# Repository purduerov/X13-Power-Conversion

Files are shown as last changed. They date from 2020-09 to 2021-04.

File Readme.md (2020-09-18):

# Readme for X13-Power-Conversion

Whenever you make a new part, download the datasheet and save it here _**and**_ with the part in the parts library

Always pull other people's changes before beginning to work
`git pull`

Be sure to push your changes after  working on them. Run:
1. `git add .` to add any files in this directory or a subdirectory
or `git add -u` to add any modified files
2. (Optional) `git clean -nX` to see what ignored files can be removed
	`git clean -fX` removes ignored files (Eagle backups)
3. `git commit -m "helpful commit message"` with a description of the work that you did
4. `git push` to push your work to github

Other helpful commands
* `git status` says information about modified and staged files
* `git log` shows the recent commits of the repository
* `git log filename.extension` show the recent commits for just that file
* `git checkout first-couple-letter-of-commit-id` lets you go back to a previous version
* `git checkout master` brings you back to the latest commit
* `git tag` lists the tags
* `git tag -a orderX -m "the version of the board placed for the X'th order"` tag a specific commit
* `git push --tags` needed to push tags to remote
* `git show orderX` show the commit log for the given tag
* `git checkout orderX` go back and interact with the files at the tagged commit

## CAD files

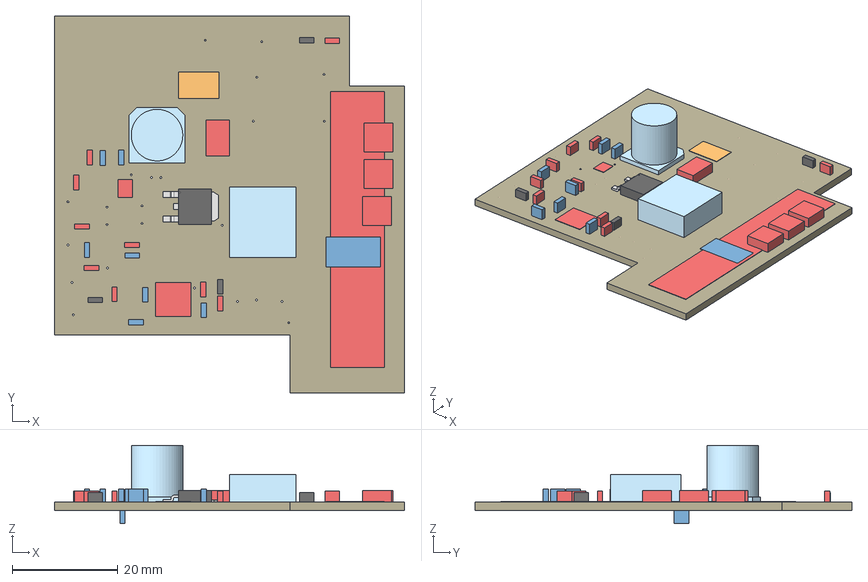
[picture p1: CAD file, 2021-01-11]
PowerConversionBoard.step
66.0 x 71.1 x 14.7 mm
Board
BANANA_CONN x 3
LED-0603 x 3
1.2 Ohms x 9
AZ1117EH-3.3TRG1
LM5085
SO08
4.7uF x 8
47uF
100uF
SWITCHMODE_SCHOTTKY
CON2DIST
15uH

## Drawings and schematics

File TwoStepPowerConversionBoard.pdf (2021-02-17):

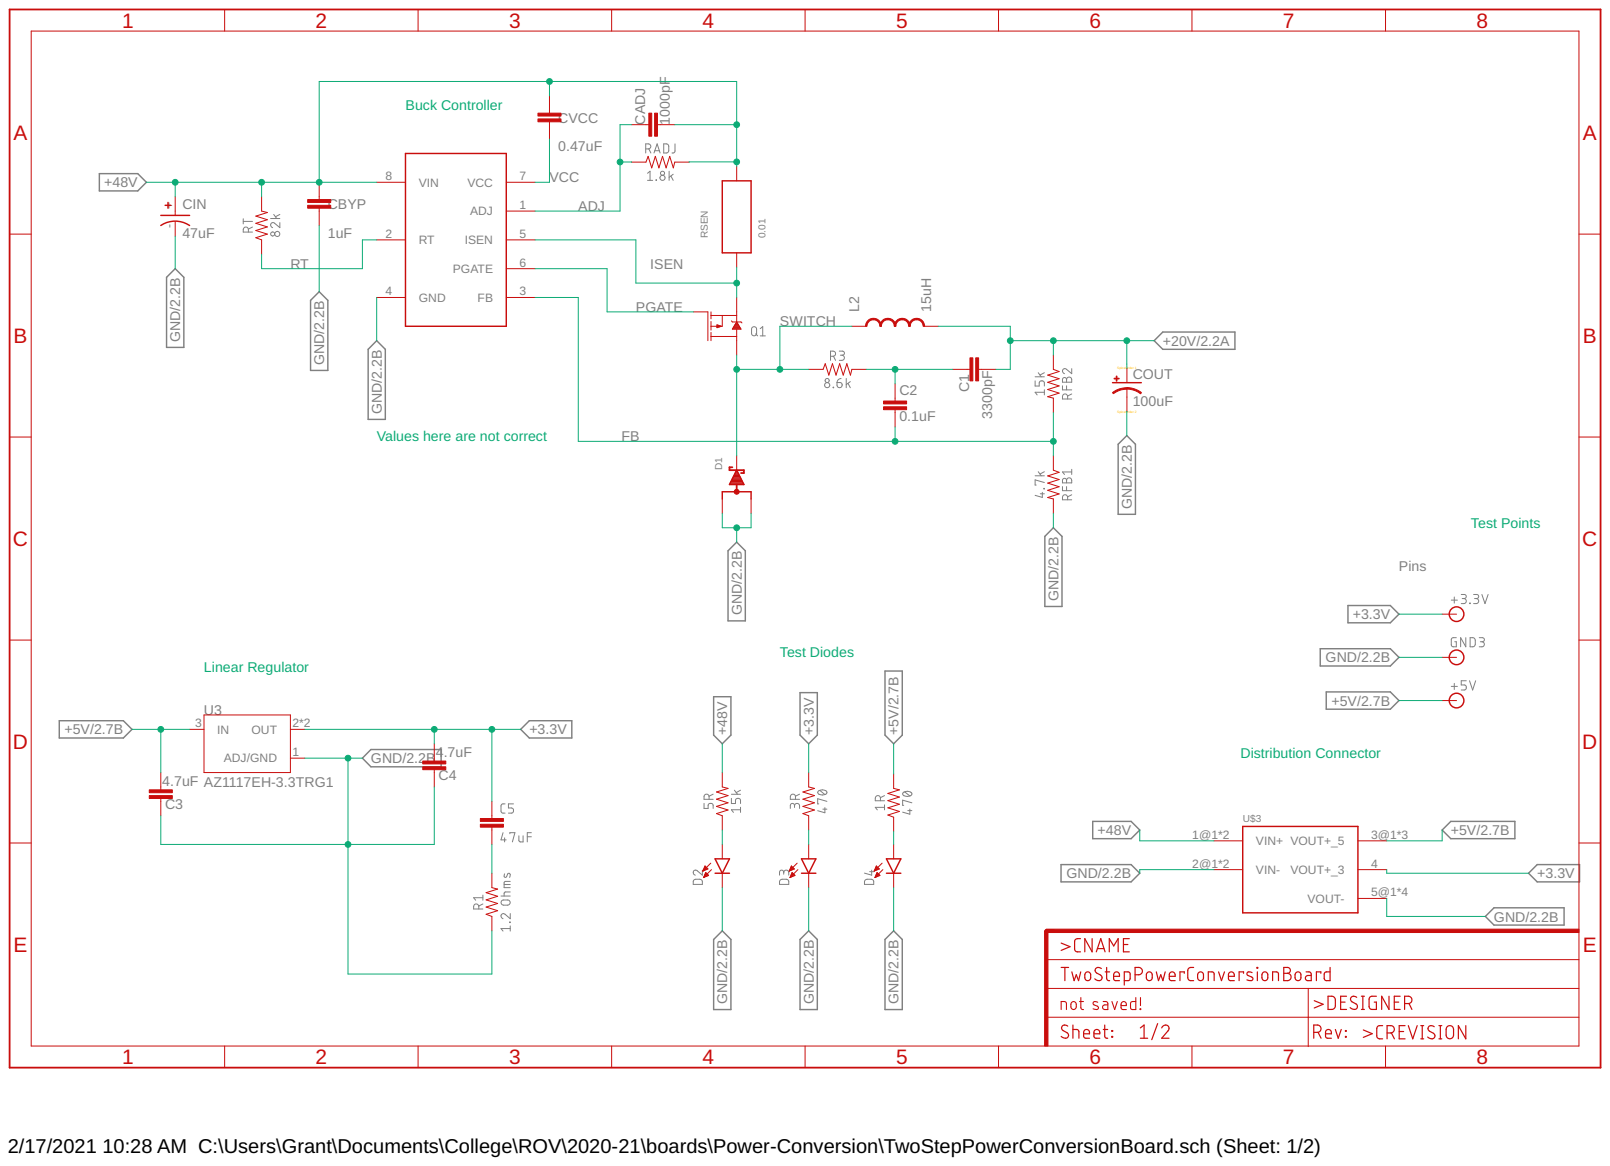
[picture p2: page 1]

Values here are not correct

2/17/2021 10:28 AM C:\Users\Grant\Documents\College\ROV\2020-21\boards\Power-Conversion\TwoStepPowerConversionBoard.sch (Sheet: 1/2)

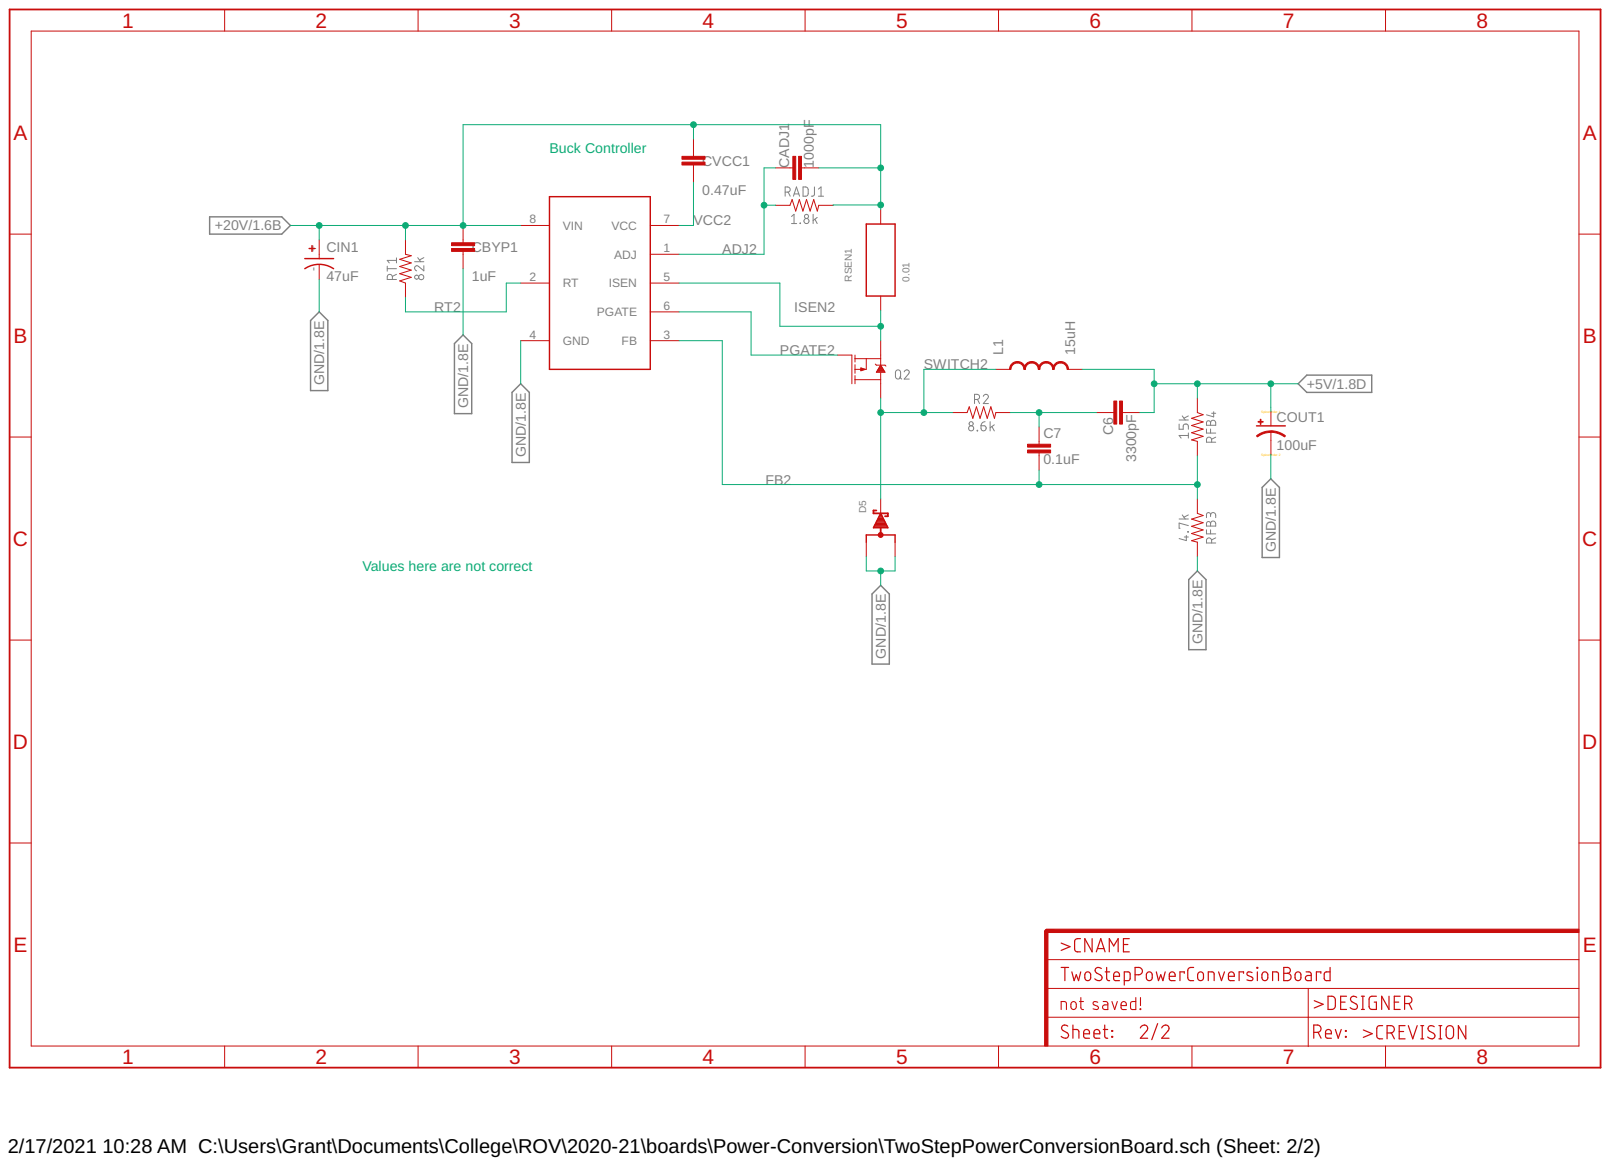
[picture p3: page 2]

Values here are not correct

2/17/2021 10:28 AM C:\Users\Grant\Documents\College\ROV\2020-21\boards\Power-Conversion\TwoStepPowerConversionBoard.sch (Sheet: 2/2)

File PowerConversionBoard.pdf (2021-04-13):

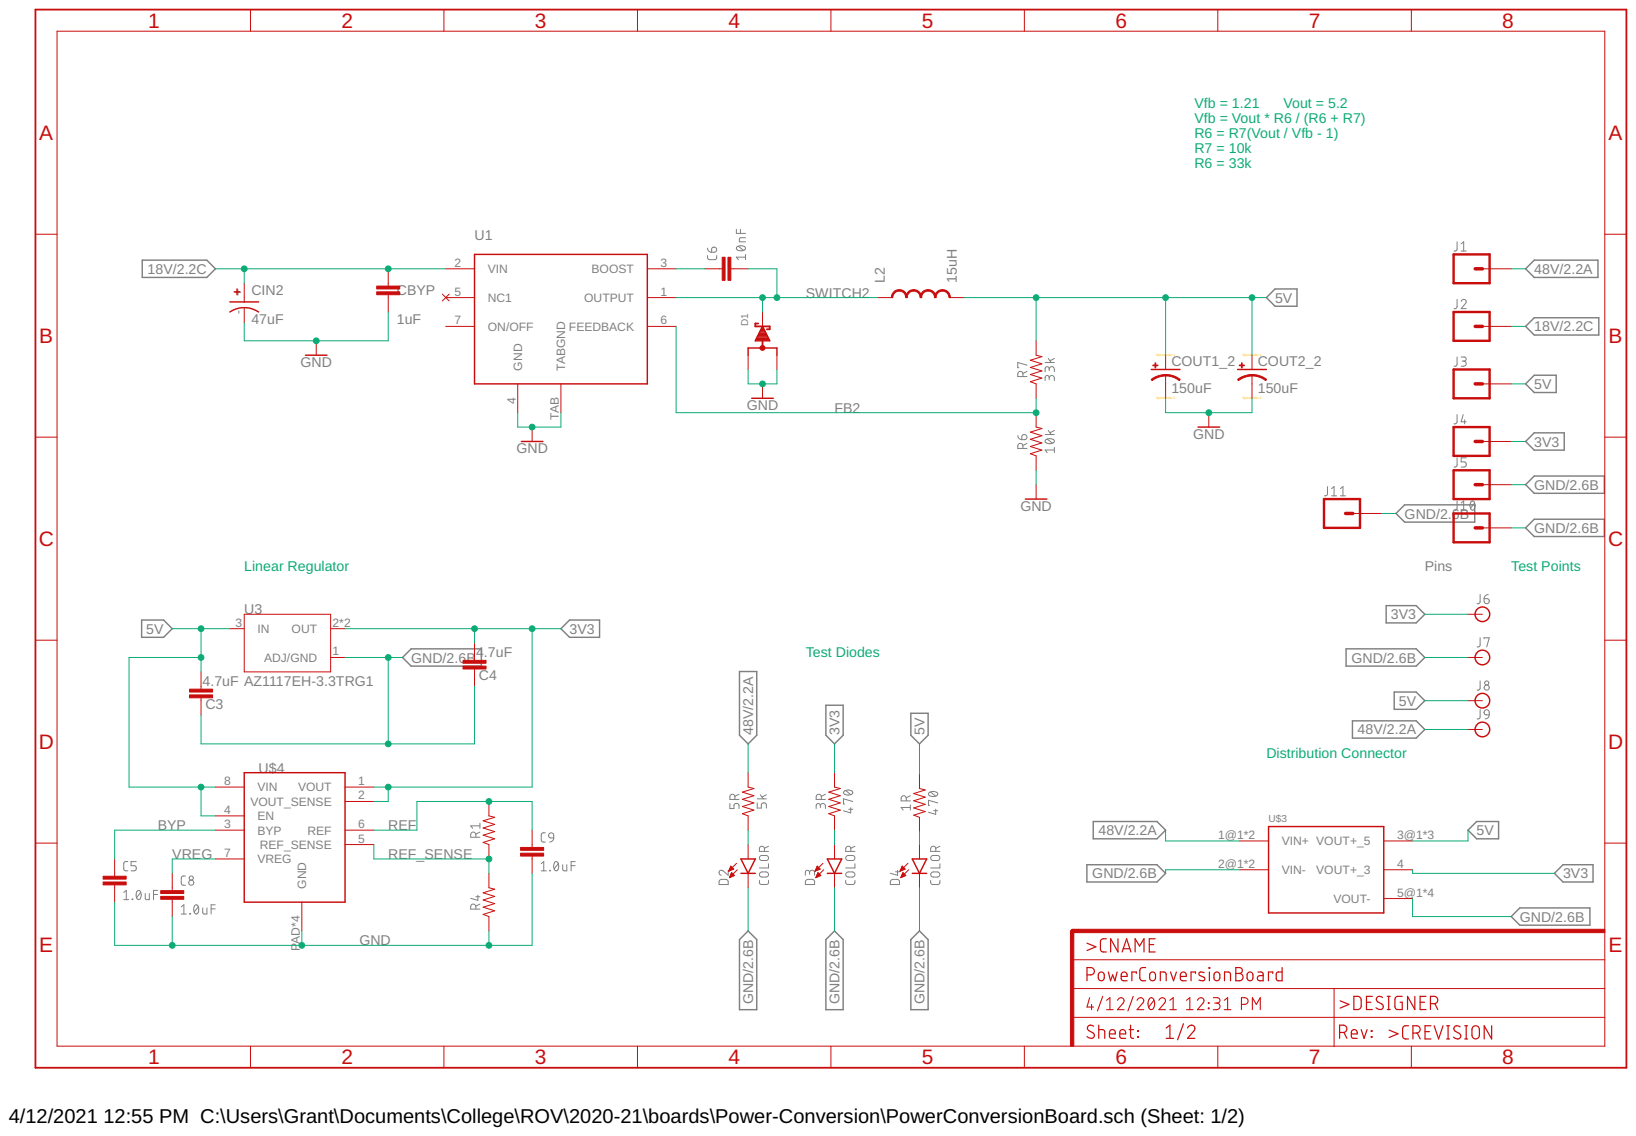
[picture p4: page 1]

4/12/2021 12:55 PM C:\Users\Grant\Documents\College\ROV\2020-21\boards\Power-Conversion\PowerConversionBoard.sch (Sheet: 1/2)

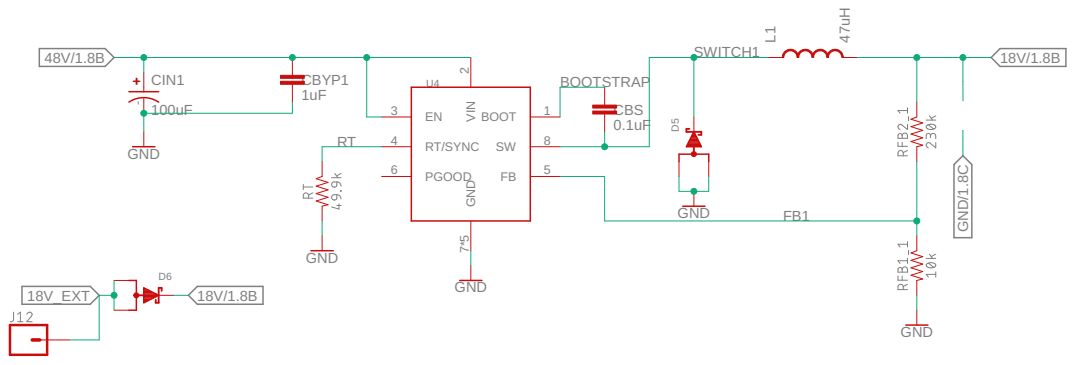
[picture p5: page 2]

4/12/2021 12:55 PM C:\Users\Grant\Documents\College\ROV\2020-21\boards\Power-Conversion\PowerConversionBoard.sch (Sheet: 2/2)

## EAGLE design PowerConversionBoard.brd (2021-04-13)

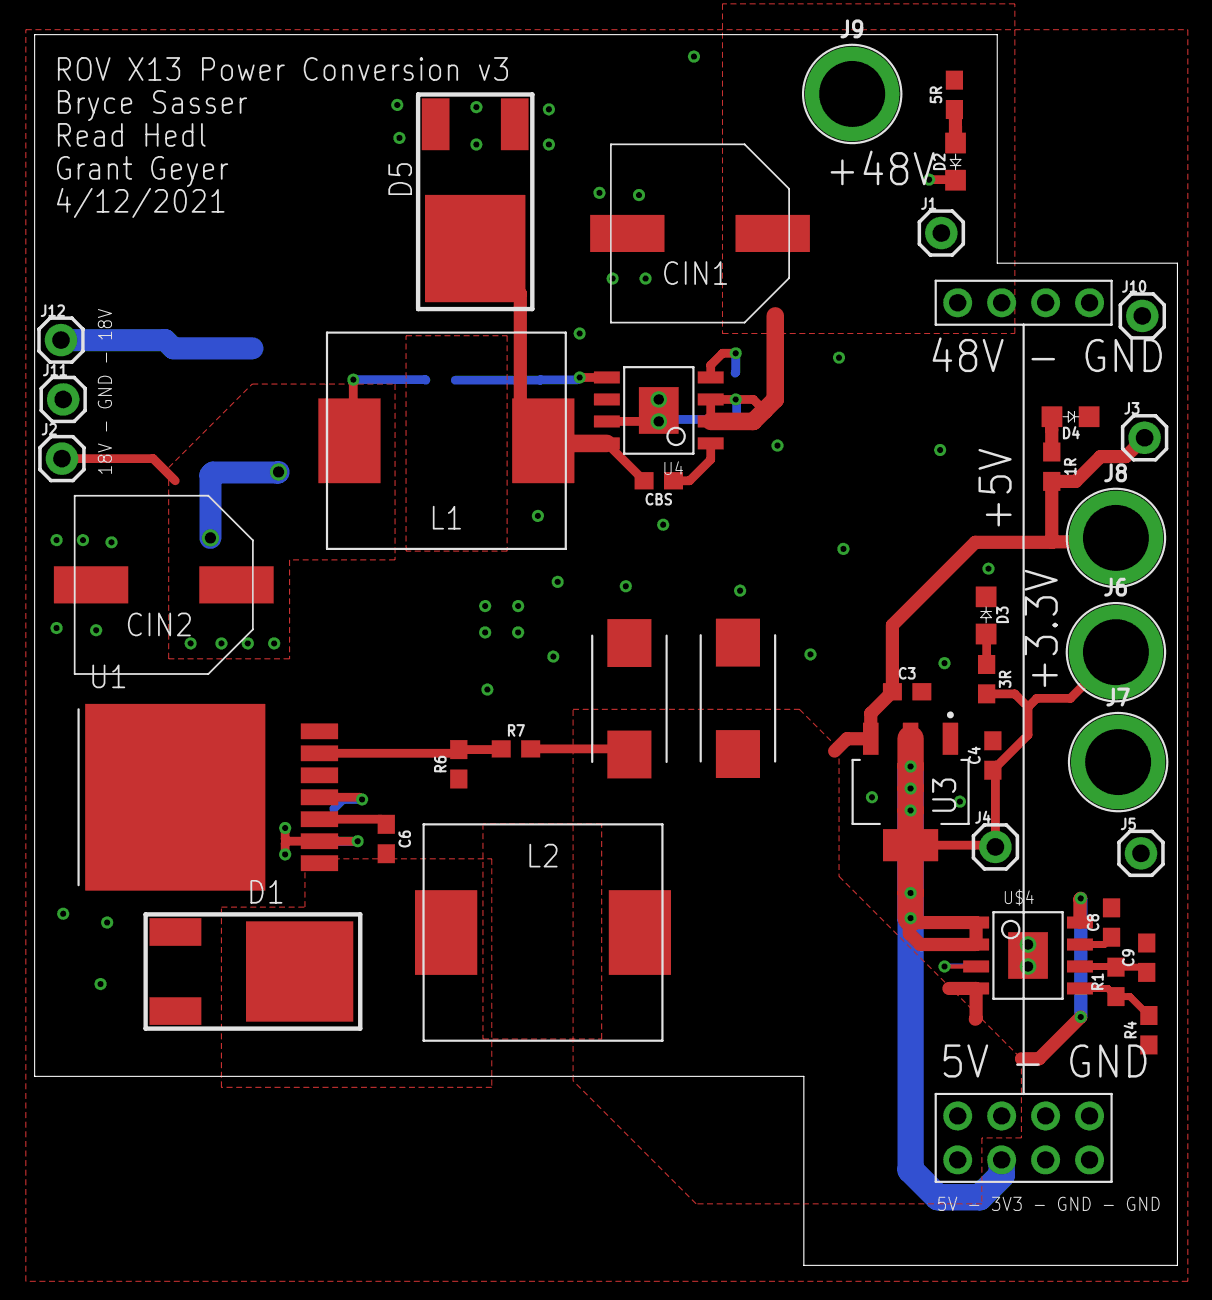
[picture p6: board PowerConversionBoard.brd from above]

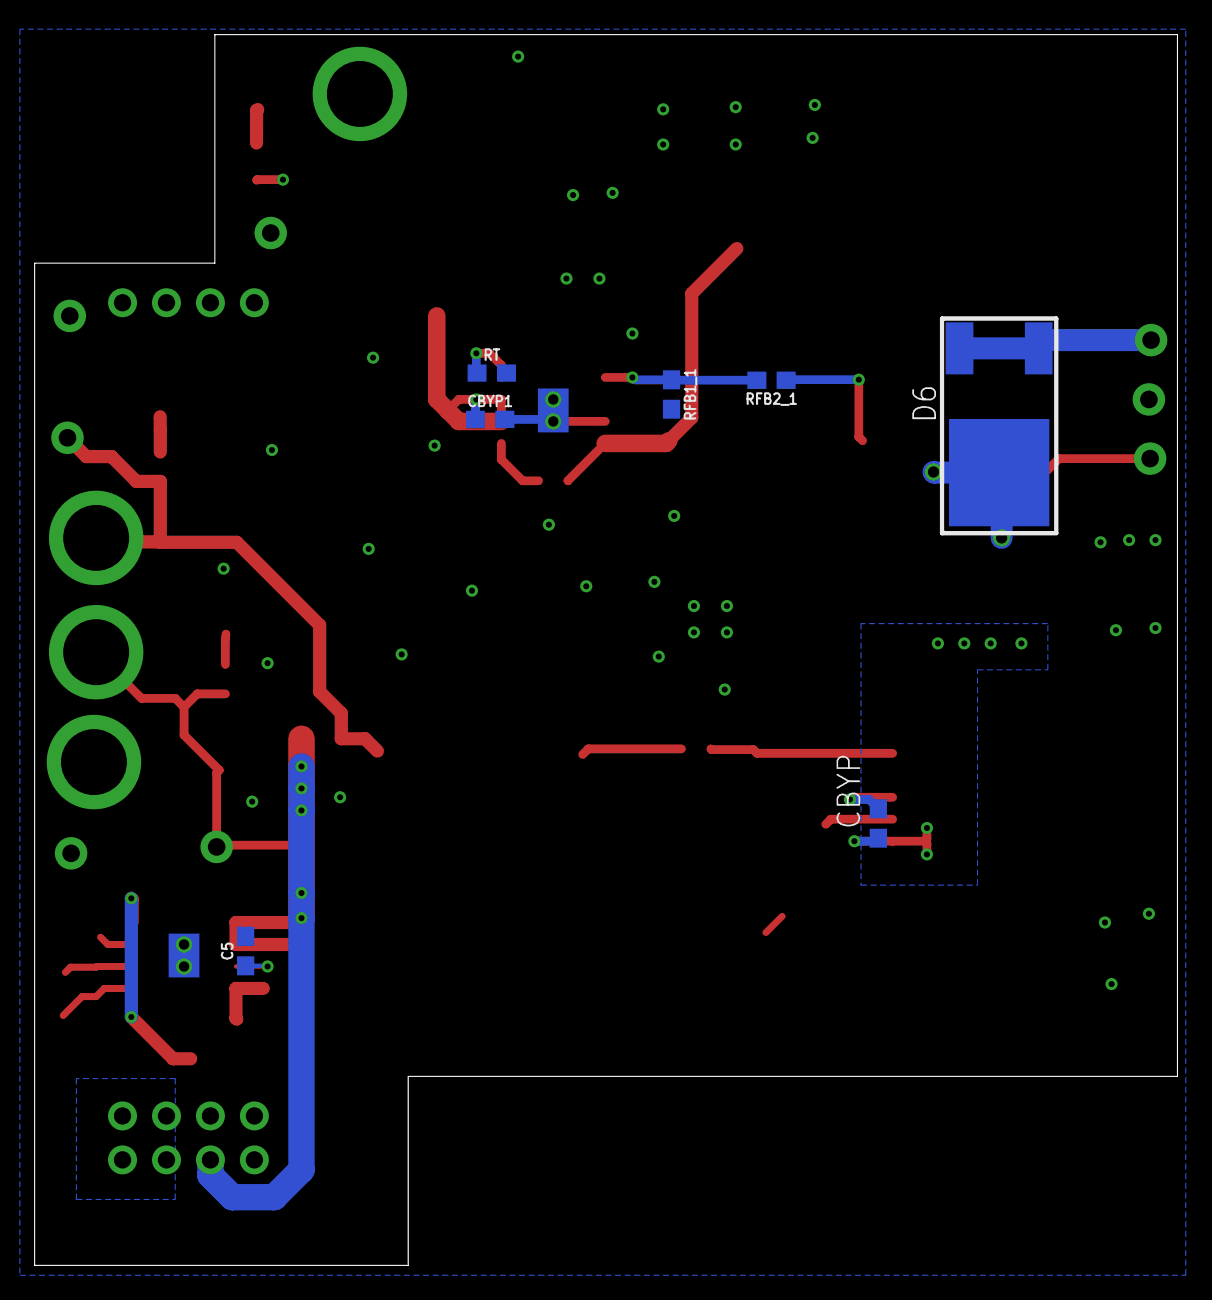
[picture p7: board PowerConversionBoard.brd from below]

Board: 2 copper layers, 66.0 x 71.1 mm, 48 parts (7 on the bottom side), 20 nets.

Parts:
1R, 3R: 470; 0603
5R: 5k; 0603
C3, C4: 4.7uF; 0603
C5, C8, C9: 1.0uF; 0603
C6: 10nF; 0603
CBS: 0.1uF; 0603
CBYP, CBYP1: 1uF; 0603
CIN1: 100uF; CAPAE1030X1050N
CIN2: 47uF; CAPAE1030X1050N
COUT1_2, COUT2_2: 150uF; CTAN(7.30_4.30MM)
D1, D5, D6: SWITCHMODE_SCHOTTKY; DPAK-3
D2, D3, D4: COLOR; 0805
J1, J2, J3, J4, J5, J10, J11, J12: 1X01
J6, J7, J8, J9: BANANA_CONN_NO_THERM
L1: 47uH; HCMA1305
L2: 15uH; HCMA1305
R1, R4: 0603
R6: 10k; 0603
R7: 33k; 0603
RFB1_1: 10k; 0603
RFB2_1: 230k; 0603
RT: 49.9k; 0603
U1: LM2678; D2PAK/TO-263
U3: AZ1117EH-3.3TRG1; SOT230P700X180-4N
U4: 8-SOIC-EP
U$3: CON2DIST
U$4: ADP7159ARDZ-04-R7; 8-SOIC-EP

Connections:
3V3: 3R.2, C4.1, J4.1, J6.1, U3.2, U3.4, U$3.4, U$4.1, U$4.2
5V: 1R.2, C3.1, COUT1_2.+, COUT2_2.+, J3.1, J8.1, L2.2, R7.2, U3.3, U$3.3@1, U$3.3@2, U$3.3@3, U$4.4, U$4.8
18V: CBYP.1, CIN2.+, D6.4, J2.1, L1.2, RFB2_1.1, U1.2
18V_EXT: D6.1, D6.3, J12.1
48V: 5R.2, CBYP1.1, CIN1.+, J1.1, J9.1, U4.2, U4.3, U$3.1@1, U$3.1@2
BOOTSTRAP: CBS.1, U4.1
BST: C6.1, U1.3
BYP: C5.1, U$4.3
FB1: RFB1_1.1, RFB2_1.2, U4.5
FB2: R6.2, R7.1, U1.6
GND: C3.2, C4.2, C5.2, C8.2, C9.2, CBYP.2, CBYP1.2, CIN1.-, CIN2.-, COUT1_2.-, COUT2_2.-, D1.1, D1.3, D2.C, D3.C, D4.C, D5.1, D5.3, J5.1, J7.1, J10.1, J11.1, R4.1, R6.1, RFB1_1.2, RT.2, U1.4, U1.TAB, U3.1, U4.7, U4.PAD, U4.PAD_BOT, U4.PAD_VIA1, U4.PAD_VIA2, U$3.2@1, U$3.2@2, U$3.5@1, U$3.5@2, U$3.5@3, U$3.5@4, U$4.PAD, U$4.PAD_BOT, U$4.PAD_VIA1, U$4.PAD_VIA2
unnamed: 5R.1, D2.A
unnamed: 3R.1, D3.A
unnamed: 1R.1, D4.A
REF: C9.1, R1.2, U$4.6
REF_SENSE: R1.1, R4.2, U$4.5
RT: RT.1, U4.4
SWITCH1: CBS.2, D5.4, L1.1, U4.8
SWITCH2: C6.2, D1.4, L2.1, U1.1
VREG: C8.1, U$4.7

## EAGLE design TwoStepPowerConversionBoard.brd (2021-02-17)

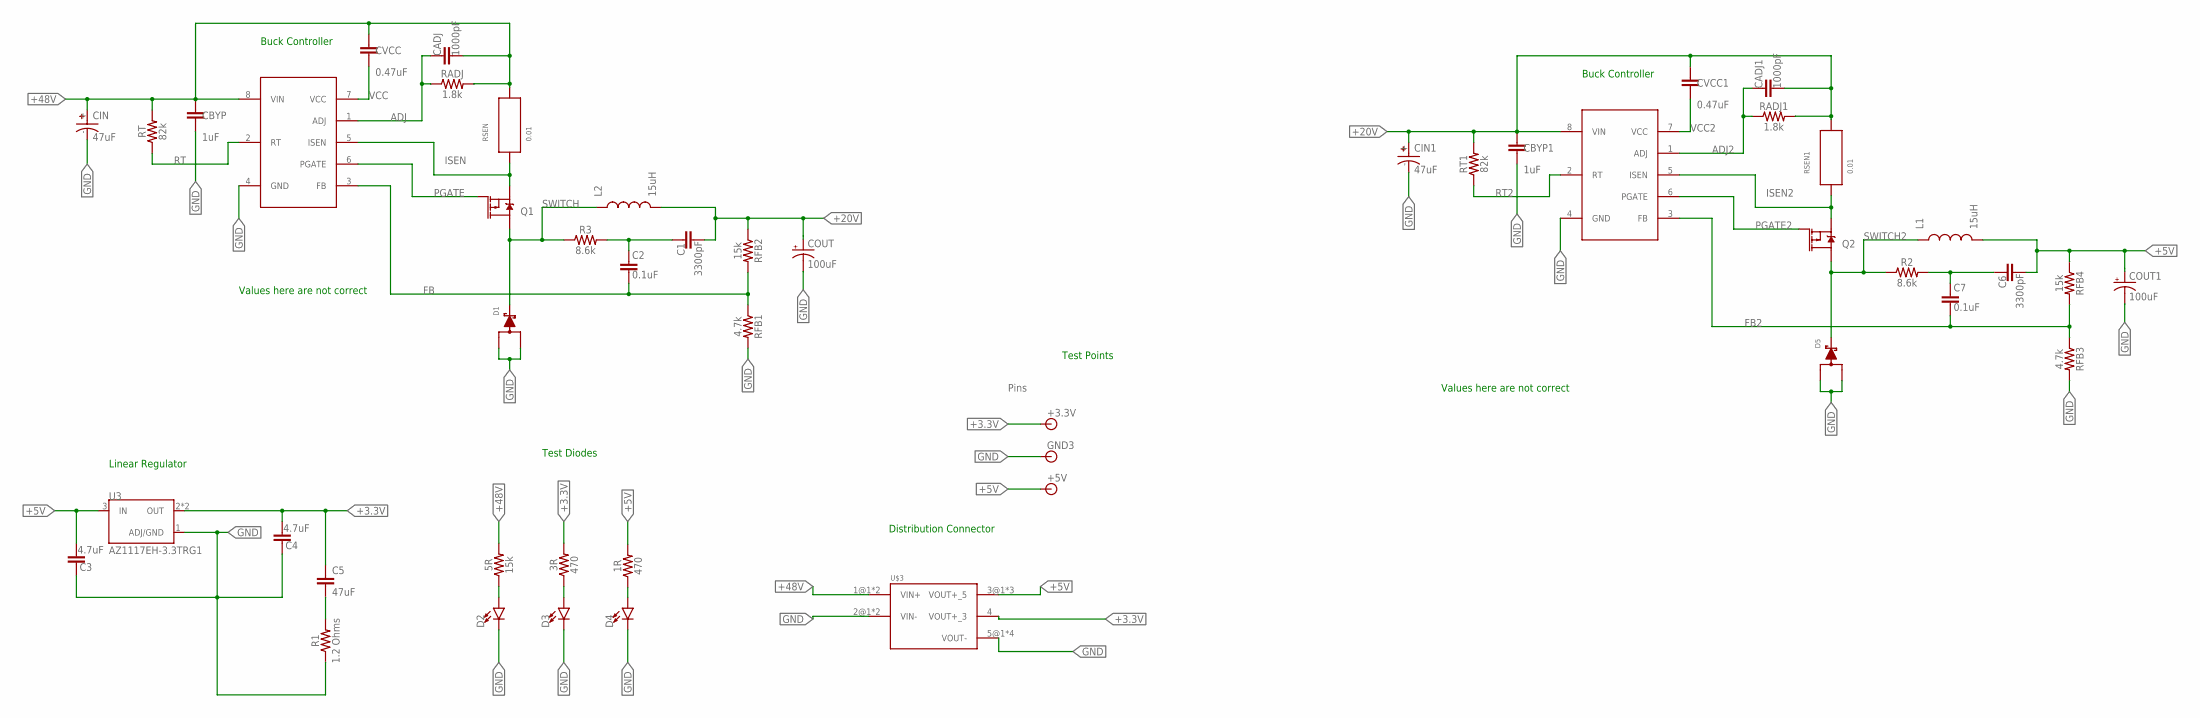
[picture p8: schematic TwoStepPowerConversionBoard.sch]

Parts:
1R, 3R: 470; 0603
5R: 15k; 0603
+3.3V, +5V: BANANA_CONN
C1, C6: 3300pF; 0603
C2, C7: 0.1uF; 0603
C3, C4: 4.7uF; 0603
C5: 47uF; 0603
CADJ, CADJ1: 1000pF; 0603
CBYP, CBYP1: 1uF; 0603
CIN, CIN1: 47uF; CAPAE1030X1050N
COUT, COUT1: 100uF; CTAN(7.30_4.30MM)
CVCC, CVCC1: 0.47uF; 0603
D1, D5: SWITCHMODE_SCHOTTKY; DPAK-3
D2, D3, D4: LED0603; LED-0603
GND3: BANANA_CONN
L1, L2: 15uH; HCMA1305
Q1, Q2: MOSFET_PCH-NDS8434; SO08
R1: 1.2 Ohms; 0603
R2, R3: 8.6k; 0603
RADJ, RADJ1: 1.8k; 0603
RFB1, RFB3: 4.7k; 0603
RFB2, RFB4: 15k; 0603
RSEN, RSEN1: 0.01; CSS2H-2512
RT, RT1: 82k; 0603
U3: AZ1117EH-3.3TRG1; SOT230P700X180-4N
U$1, U$2: LM5085
U$3: CON2DIST

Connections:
+3.3V: 3R.2, +3.3V.P$1, C4.1, C5.1, U3.2 (OUT), U3.4 (OUT), U$3.4 (VOUT+_3)
+5V: 1R.2, +5V.P$1, C3.1, C6.1, COUT1.+, L1.2, RFB4.1, U3.3 (IN), U$3.3@1 (VOUT+_5), U$3.3@2 (VOUT+_5), U$3.3@3 (VOUT+_5)
+20V: C1.1, CADJ1.2, CBYP1.1, CIN1.+, COUT.+, CVCC1.1, L2.2, RADJ1.2, RFB2.1, RSEN1.2, RT1.2, U$2.8 (VIN)
+48V: 5R.2, CADJ.2, CBYP.1, CIN.+, CVCC.1, RADJ.2, RSEN.2, RT.2, U$1.8 (VIN), U$3.1@1 (VIN+), U$3.1@2 (VIN+)
ADJ: CADJ.1, RADJ.1, U$1.1 (ADJ)
ADJ2: CADJ1.1, RADJ1.1, U$2.1 (ADJ)
FB: C2.2, RFB1.1, RFB2.2, U$1.3 (FB)
FB2: C7.2, RFB3.1, RFB4.2, U$2.3 (FB)
GND: C3.2, C4.2, CBYP.2, CBYP1.2, CIN.-, CIN1.-, COUT.-, COUT1.-, D1.1 (A), D1.3 (A), D2.C, D3.C, D4.C, D5.1 (A), D5.3 (A), GND3.P$1, R1.1, RFB1.2, RFB3.2, U3.1 (ADJ/GND), U$1.4 (GND), U$2.4 (GND), U$3.2@1 (VIN-), U$3.2@2 (VIN-), U$3.5@1 (VOUT-), U$3.5@2 (VOUT-), U$3.5@3 (VOUT-), U$3.5@4 (VOUT-)
ISEN: Q1.1 (S), Q1.2 (S), Q1.3 (S), RSEN.1, U$1.5 (ISEN)
ISEN2: Q2.1 (S), Q2.2 (S), Q2.3 (S), RSEN1.1, U$2.5 (ISEN)
unnamed: C6.2, C7.1, R2.2
unnamed: 5R.1, D2.A
unnamed: 3R.1, D3.A
unnamed: 1R.1, D4.A
unnamed: C1.2, C2.1, R3.2
unnamed: C5.2, R1.2
PGATE: Q1.4 (G), U$1.6 (PGATE)
PGATE2: Q2.4 (G), U$2.6 (PGATE)
RT: RT.1, U$1.2 (RT)
RT2: RT1.1, U$2.2 (RT)
SWITCH: D1.4 (C), L2.1, Q1.5 (D), Q1.6 (D), Q1.7 (D), Q1.8 (D), R3.1
SWITCH2: D5.4 (C), L1.1, Q2.5 (D), Q2.6 (D), Q2.7 (D), Q2.8 (D), R2.1
VCC: CVCC.2, U$1.7 (VCC)
VCC2: CVCC1.2, U$2.7 (VCC)

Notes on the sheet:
Pins
Linear Regulator
Buck Controller
Test Diodes
Test Points
Distribution Connector
Values here are not correct

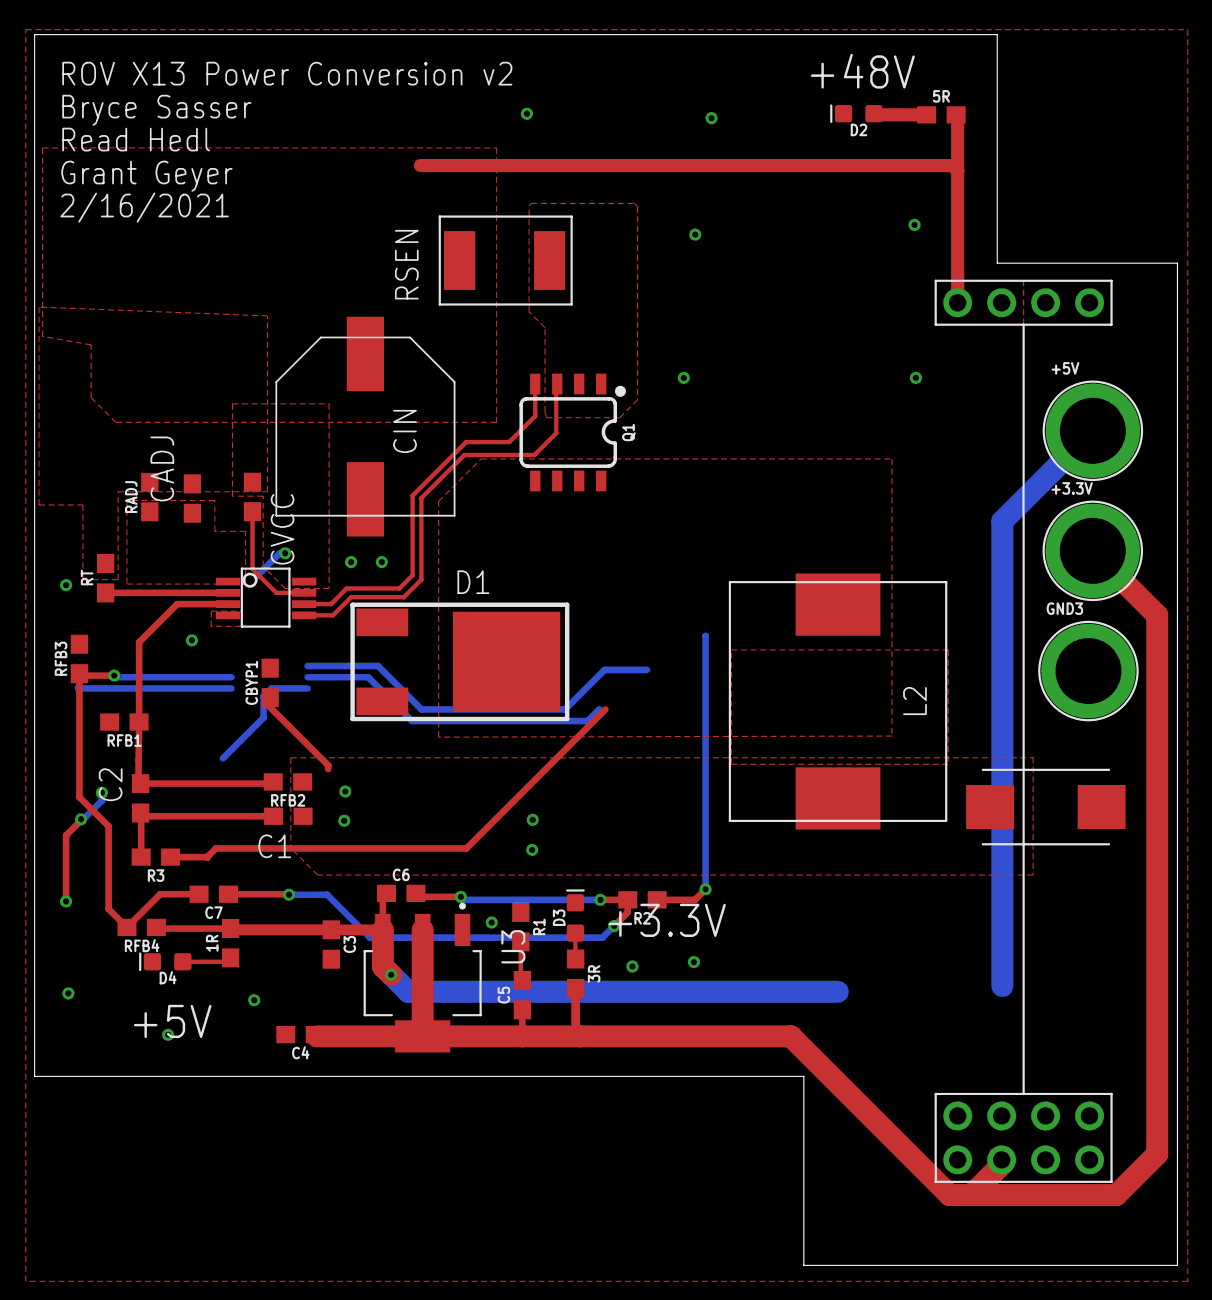
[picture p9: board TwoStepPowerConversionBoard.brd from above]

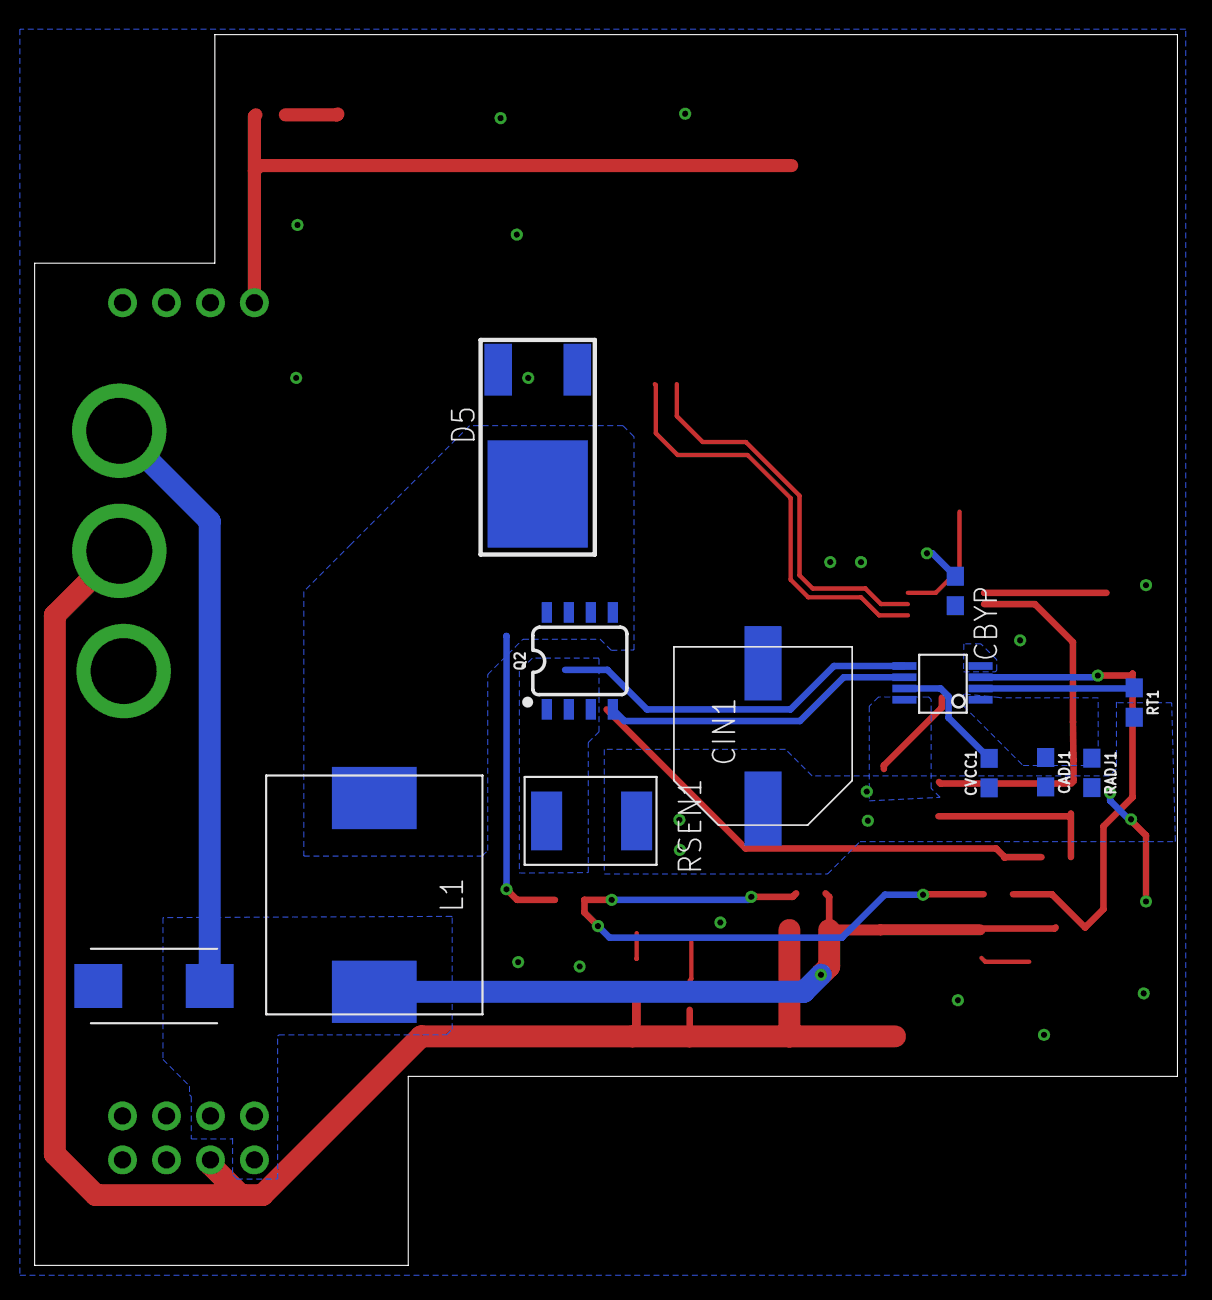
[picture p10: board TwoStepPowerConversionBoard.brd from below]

Board: 2 copper layers, 66.0 x 71.1 mm, 49 parts (12 on the bottom side), 25 nets.

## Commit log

2020-10-17 Updated the old board for 48V and added the new voltage regulator; still need to include connector to power distribution
    [PowerConversionBoard.brd, PowerConversionBoard.sch]
2020-10-17 added the power ditribution connector
    [PowerConversionBoard.brd, PowerConversionBoard.sch]
2020-10-25 Align schematic to 0.1 in. Create board with dimension
    [PowerConversionBoard.brd, PowerConversionBoard.sch]
2020-10-31 Added the connector to the distribution board
    [PowerConversionBoard.brd, PowerConversionBoard.sch]
2020-11-14 made progress on the buck controller supporting circuitry
    [PowerConversionBoard.brd, PowerConversionBoard.sch]
2020-11-16 threw the pieces onto the board in no particular order and finsihed the skeleton of the circuit around the buck controller. Still need to get the standard values for the inductors and capacitors, but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
    [PowerConversionBoard.brd, PowerConversionBoard.sch]
2020-12-05 Changed Buck Controller output to 5.2V (did not change net label); added RC Circuit to Linear regulator; added connection to distribution board
    [PowerConversionBoard.brd, PowerConversionBoard.sch]
2020-12-05 Copied in last year's capacitor and inductor
    [PowerConversionBoard.brd, PowerConversionBoard.sch]
2020-12-05 copied old parts over
    [PowerConversionBoard.brd, PowerConversionBoard.sch]
2020-12-05 routed the board
    [PowerConversionBoard.brd, PowerConversionBoard.sch]
2020-12-05 wrong inductor previously. oops
    [PowerConversionBoard.brd, PowerConversionBoard.sch]
2020-12-05 routed everything (except ground) hopefully right
    [PowerConversionBoard.brd]
2020-12-05 Finished all the routing
    [PowerConversionBoard.brd, PowerConversionBoard.sch]
2020-12-06 Fixed an air wire I missed earlier
    [PowerConversionBoard.brd]
2020-12-06 Fixed it for real this time\
    [PowerConversionBoard.brd]
2021-01-03 Fixed wire sizing and some of the angles on the board
    [PowerConversionBoard.brd]
2021-01-05 Rough draft of the new and improved board finished; need to work out wires connecting to polygons and probably clean up the test points; there are also a few strange wiring places that need to be cle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
    [PowerConversionBoard.brd, PowerConversionBoard.sch]
2021-01-06 Pretty much finished the layput of the board, but a few minor changes still need to be made; awaiting dimensions of potential cutoffs
    [PowerConversionBoard.brd, PowerConversionBoard.sch]
2021-01-07 smaller board outline
    [PowerConversionBoard.brd, PowerConversionBoard.sch]
2021-01-07 Renamed the nets and inceased wire size where it was reasonable. Also moved around some components for strighter wiring.
    [PowerConversionBoard.brd, PowerConversionBoard.sch]
2021-01-10 Finished the board and added the text
    [PowerConversionBoard.brd, PowerConversionBoard.sch]
2021-01-10 Cleaning up git and adding exports for ordering
    [PowerConversionBoard.brd, PowerConversionBoard.sch, PowerConversionBoard.step]
2021-01-11 playing with 3d models generated by eagle package
    [PowerConversionBoard.brd, PowerConversionBoard.sch, PowerConversionBoard.step]
2021-02-17 Reeeeeeeeeev 2 on the red line
    [PowerConversionBoard.brd, PowerConversionBoard.sch]
2021-02-17 Finished mapping the board for the two step process. The correct values are not calculated for either step of the conversion.
    [TwoStepPowerConversionBoard.brd, TwoStepPowerConversionBoard.sch]
2021-02-17 Larger LEDs on main and graphic and text on the other
    [PowerConversionBoard.brd, PowerConversionBoard.sch, TwoStepPowerConversionBoard.brd]
2021-04-13 V3 with buck converter of previous years
    [PowerConversionBoard-schematic.sch, PowerConversionBoard.brd]

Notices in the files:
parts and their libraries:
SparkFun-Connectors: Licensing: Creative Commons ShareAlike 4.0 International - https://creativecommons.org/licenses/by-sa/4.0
